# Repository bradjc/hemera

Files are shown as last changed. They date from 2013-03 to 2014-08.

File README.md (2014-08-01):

Hemera Indoor Sensor Node
=========================

Hemera is an indoor wireless sensor node that measures temperature, humidity, light and motion.

The node contains three key sensors:
- Sensirion SHT11 (Temperature and Humidity)
- Rohm BH1721 (Light)
- PIR (Motion)

hemera (http://www.bradcampbell.com/wp-content/uploads/2012/05/hemera_project.jpg)

Setup
-----

### 1) Clone &amp; install the Lab11 version of tinyos-main:

    git clone https://github.com/lab11/tinyos-main.git
    cd tinyos-main/tools
    ./Bootstrap
    ./configure
    make
    sudo make install

### 2) Clone yours truly:

    git clone https://github.com/lab11/hemera.git

### 3) Add to `bash.rc`:

    export TINYOS_ROOT_DIR=<path to>/tinyos-main
    export TINYOS_ROOT_DIR_ADDITIONAL=<path to>/hemera/tinyos:$TINYOS_ROOT_DIR_ADDITIONAL

### 4) Set up the RaspberryPi (optional, but recommended):

A modified RaspberryPi can be utilized to receive and forward data to GATD. 
If you choose to use one, you need the [Linux CC2520 Driver](https://github.com/ab500/linux-cc2520-driver) for the RPi.
Instead of installing this manually, it is suggested to download &amp; install the preinstalled image from [this torrent](https://github.com/lab11/raspberrypi-cc2520/tree/master/torrents).
Go to https://github.com/lab11/raspberrypi-cc2520 for additional details on setup.

Clone the RPi repo:

    git clone https://github.com/lab11/raspberrypi-cc2520.git

Add to `bash.rc`:

    export TINYOS_ROOT_DIR_ADDITIONAL=<path to>/raspberrypi-cc2520/tinyos:$TINYOS_ROOT_DIR_ADDITIONAL

### 5) Get the compilers

In order to compile the TinyOS code you need the msp430 and the ARM compilers

Sense Stuff
-----------

After you have finsihed the above setup, you should be ready to install apps on the Hemera board.

The basic sense &amp; broadcast app is HemeraAM. To install it, go to `<path to>/hemera/tinyos/apps/HemeraAM` and follow the README. 

To receive &amp; forward data to GATD on the RPi, go to `<path to>/hemera/tinyos/apps/RpiGatdForwarder` and follow the README.

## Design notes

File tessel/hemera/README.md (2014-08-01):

Hemera on Tessel
================

Want to implement Hemera on a Tessel? You've come to the right place!  

Requirements
------------

* [Tessel](http://tessel.io)
* [Climate module](https://tessel.io/modules#module-climate)
* [Ambient module](https://tessel.io/modules#module-ambient)
* Standard 3-pin PIR sensor (VCC, GND, OUT)
* [Node.js](http://nodejs.org)

Setup
-----

The assumed module connections are as follows:
- Ambient Module -> Port A
- Climate Module -> Port B
- PIR Sensor -> Port D ( GND -> G1, VCC -> G2, OUT -> G3 )

This, along with HTTP POST destination (default:GATD), can be changed by modifying `hemera.js`.

Installation
------------

If you have yet to do so, [install Node.js & Tessel](http://start.tessel.io/install).

Install the modules:

    npm install ambient-attx4
    npm install climate-si7005
    npm install climate-si7020

Connect to WiFi:

    tessel wifi -n [network name] -p [password]

Run:

    tessel run hemera.js

Save on Tessel to run automatically:

    tessel push hemera.js

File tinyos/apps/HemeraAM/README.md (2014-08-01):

HemeraAM
========
@author Thomas Zachariah
@url    http://github.com/lab11/hemera

Overview
--------

HemeraAM samples temperature, humidity, light, and motion, 
and sends the recorded data via Active Message. 

Installation
------------

Options are located in the Makefile.
Sampling Period & Radio Channel may be adjusted there.

RUN:

    ./install #

(where # is the intended id number of the device) OR

    make hemera install miniprog bsl,/dev/ttyUSB0

When using the install script or the alternate command,
ensure location (`/dev/ttyUSB?`) is correct.

Verification
------------

To verify broadcast, press the user button on the back:
- If the program is running, the green LED will turn on.
- If it is sending packets, the blue LED will toggle.
- If an error is encountered, the red LED will toggle.

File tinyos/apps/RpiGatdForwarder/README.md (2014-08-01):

RpiGatdForwarder
========
@author Thomas Zachariah
@url    http://github.com/lab11/hemera

Overview
--------

RpiGatdForwarder accepts all incoming packets on a channel,
and forwards them to a server (GATD).

Installation
------------

Configure the settings in the Makefile. Then run:

    make rpi install scp.<ip address of the RPi>

Alternatively, you can copy the precompiled app `RpiGatdForwarderC` (runs using default settings) directly to the home directory of the Raspberry Pi.

Run
---

On the Raspberry Pi, run:

    sudo ~/RpiGatdForwarderC

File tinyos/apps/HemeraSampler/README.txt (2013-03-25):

README for a HemeraSampler
@author Brad Campbell
@url http://whereabouts.eecs.umich.edu/wiki/doku.php?id=tinyos_HemeraSampler

** Quick Overview **

HemeraSampler is a straightforward app for using the sensors on the hemera board.
It samples the temperature, humidity, and light sensors. Also reports motion.

Uses Blip 2.0.

** Installation Directions **

The options are located in the Makefile. You can choose how often to sample and
where the packets should be sent to.

make epic blip install miniprog

Run the python mysql listener in $TOSROOT/support/sdk/python/tinyos/listener

** More Info **

http://whereabouts.eecs.umich.edu/wiki/doku.php?id=tinyos_HemeraSampler

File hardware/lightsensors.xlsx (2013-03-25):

Sensor | cost | average current | interface | notes
Si1120 | have (2.64) | 10u | PWM | * pwm length has to be converted to lux, and there aren't equations, just graphs * seems to be designed for its proximity sensing abilities, not ambient light sensing
Avago APDS-9300 | 1.88 (1.65 for 10) | 3.2u sleep, .24m active | i2c Fast-Mode | * controlled by 16 registers that can be written to/read from with i2c * can switch between low gain and high gain * can trigger an interrupt on many different events * have to convert sensor output to "sensor lux" (which is typically == "actual lux")
Rohm BH1721FVC | 2.39 (1.9 for 25) | .01u sleep, .140m active | i2c Fast-Mode | * to use: write an opcode, then issue a read * convert output to lux by dividing by 1.2 * extra async reset port to deal with * no adjustable gain * few different models with varying precision and packages * no interrupt option * have new models that dont need annoying reset, but i can't find them to buy

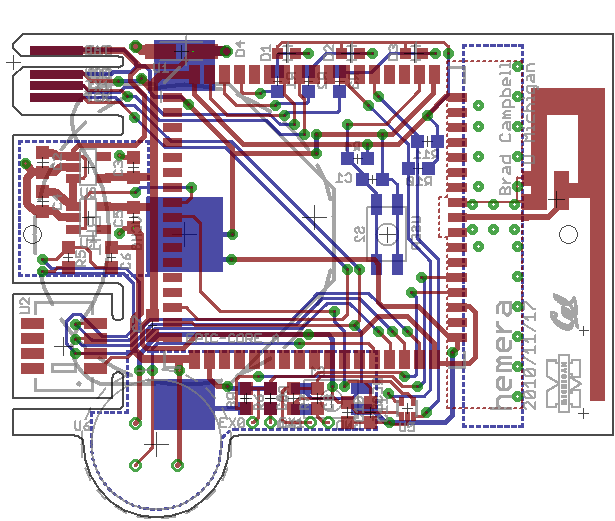
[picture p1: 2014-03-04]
hardware/eagle/rev_c/hemera_C_pcb.png

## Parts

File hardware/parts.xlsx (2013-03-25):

Parts in Hemera (Whereabouts) Box
Part Number | Description | Per | Needed |  |  |  |  |  | Quantity
 |  |  | 10 |  | 25 |  | 50 |  | 2010-11-04 | 2011-03-14 | 2011-08-04 | 2011-10-04
hemera | pcb | 1 | 10 | 0 | 25 | -15 | 50 | -40 |  |  | 10 | 80
MIC5231-3 | 3V Regulator | 1 | 10 | 4 | 25 | -11 | 50 | -36 | 17 | 16 | 14 | 0
MIC5235-3 | 3V Regulator | 1 | 10 | 4 | 25 | -11 | 50 | -36 | 17 | 16 | 14 | 0
SD103AW-TP | 40V Diode | 1 | 10 | 5 | 25 | -10 | 50 | -35 | 16 | 15 | 15 | 9
3008 | battery clip | 1 | 10 | 2 | 25 | -13 | 50 | -38 | 17 | 17 | 12 | 32
10uF | capacitor | 4 | 40 | 185 | 100 | 125 | 200 | 25 | 80 | 83 | 225 | 117
0.1uF | capacitor | 7 | 70 | 230 | 175 | 125 | 350 | -50 | 11 | 164 | 300 | 112
blue | led | 1 | 10 | 2 | 25 | -13 | 50 | -38 | 4 | 3 | 12 | 65
red | led | 1 | 10 | 210 | 25 | 195 | 50 | 170 | 4 | 3 | 220 | 150
green | led | 1 | 10 | 5 | 25 | -10 | 50 | -35 | 5 | 4 | 15 | 65
EVQ-P2K02Q | push switch | 2 | 20 | 3 | 50 | -27 | 100 | -77 | 30 | 28 | 23 | 15
100k | resistor | 3 | 30 | 119 | 75 | 74 | 150 | -1 | 90 | 78 | 149 | 63
10k | resistor | 3 | 30 | 190 | 75 | 145 | 150 | 70 | 95 | 90 | 220 | 130
3M | resistor | 2 | 20 | 140 | 50 | 110 | 100 | 60 | 90 | 83 | 160 | 100
470 | resistor | 3 | 30 | 75 | 75 | 30 | 150 | -45 | 40 | 36 | 105 | 400
BH1721FVC-TR | light sensor | 1 | 10 | 4 | 25 | -11 | 50 | -36 |  | 4 | 14 | 4
SHT11 | sensor | 1 | 10 | -10 | 25 | -25 | 50 | -50 | 1 | 0 | 0 | 1
PIR | sensor | 1 | 10 | -10 | 25 | -25 | 50 | -50 | 1 | 0 | 0 | 1
Epic |  | 1 | 10 | -10 | 25 | -25 | 50 | -50 | 1 | 0 | 0 | 1

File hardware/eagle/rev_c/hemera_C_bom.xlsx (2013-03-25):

Bill of Material - hemera_C
Item # | Quantity | Ref Des | Digi-Key Part Number | Manuf. Part Nr. | Description | Package | Type
1 | 1 | BH1 | 3008K-ND | 3008 | RETAINER COIN CELL 24MM SMD |  | fine-pitch
2 | 7 | C1, C6, C7, C8, C9, C10, C11 |  |  | CAP CER 0.1UF | 0603 | smt
3 | 4 | C2, C3, C4, C5 | 490-3896-1-ND | GRM188R60J106ME47D | CAP CER 10UF 6.3V X5R 0603 | 0603 | smt
4 | 1 | D1 | 638-QTLP600C7 | QTLP600C7TR | RED LED | 0603 | smt
5 | 1 | D2 | P521CT-ND | LNJ308G8LRA | GREEN LED | 0603 | smt
6 | 1 | D3 | LN937W8CRACT-ND | LNJ937W8CRA | BLUE LED | 0603 | smt
7 | 1 | D4 | SD103AWTPMSCT-ND | SD103AW-TP | DIODE SCHOTTKY 40V 350MA SOD123 | custom | fine-pitch
8 | 3 | R1, R2, R3 | P470GCT-ND | ERJ-3GEYJ471V | RES 470 OHM 1/10W 5% 0603 SMD | 0603 | smt
9 | 3 | R4, R6, R7 | P100KGCT-ND | ERJ-3GEYJ104V | RES 100K OHM 1/10W 5% 0603 SMD | 0603 | smt
10 | 3 | R5, R10, R11 | RMCF0603FT10K0CT-ND | RMCF0603FT10K0 | RES 10K OHM 1/10W 1% 0603 SMD | 0603 | smt
11 | 2 | R8, R9 | P3.0MGCT-ND | ERJ-3GEYJ305V | RESISTOR 3.0M OHM 1/10W 5% 0603 | 0603 | smt
12 | 2 | S1, S2 | P11084SCT-ND | EVQ-P2K02Q | LT SWITCH 2.5MM HT 350GF SMD | custom | smt
13 | 1 | U1 |  |  | Epic core |  | smt
14 | 1 | U2 | 69c4848 | SHT11 | SHT11 TEMP?HUMIDITY SENSOR |  | smt
15 | 1 | U3 | 576-1283-1-ND | MIC5231-3.0YM5 TR | IC REG LDO 3.0V MICROPWR SOT23-5 | SOT-23 | fine-pitch
16 | 1 | U4 | 576-2783-1-ND | MIC5235-3.0YM5 TR | IC REG LDO 150MA 3.0V SOT23-5 | SOT-23 | fine-pitch
17 | 1 | U5 | BH1721FVC-CT-ND | BH1721FVC-TR | IC AMBIENT LIGHT SENSOR WSOF5 | WSOF5 | smt
18 | 1 | U6 | 255-2652-ND | AMN42122 | PIR |  | thru-hole
 |  |  |  |  | BOARD SUMMARY FOR QUOTE
 |  |  |  |  | Total # of unique parts | 18
 |  |  |  |  | SMT placements per board | 30
 |  |  |  |  | Thru-hole placements per board | 1
 |  |  |  |  | Fine pitch placements per board | 4

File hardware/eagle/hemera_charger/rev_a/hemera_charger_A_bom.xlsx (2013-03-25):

Bill of Material - hemera_charger_A
Item # | Quantity | Ref Des | Digi-Key Part Number | Manuf. Part Nr. | Description | Package | Type
1 | 4 | C1, C2, C3, C4 |  |  | CAP CER 1UF 0603 | 0603 | smd
2 | 1 | C5 |  |  | CAP CER 10UF 0603 | 0603 | smd
3 | 1 | C6 |  |  | CAP CER 22UF 0603 | 0603 | smd
4 | 1 | C7 |  |  | CAP CER 0.1UF 0603 | 0603 | smd
5 | 2 | R1, R2 |  |  | RES 1K OHM 0603 | 0603 | smd
6 | 1 | R3 |  |  | RES 1.8M OHM 0603 | 0603 | smd
7 | 1 | R4 |  |  | RES 200K OHM 0603 | 0603 | smd
8 | 1 | D1 |  |  | BLUE LED 0603 | 0603 | smd
9 | 1 | D2 |  |  | RED LED 0603 | 0603 | smd
10 | 1 | L1 |  | LPS3015-222ML | INDUCTOR 2.2 uH |  | smd
11 | 2 | U1, U2 | 700-MAX1555EZK+T | MAX1555EZK+T | Dual USB/AC 1-Cell Li+ Battery Charger | SOT23-5 | fine-pitch
12 | 1 | U3 | 296-21663-1-ND | TPS61200DRCT | IC BOOST SYNC ADJ 1.2A 10SON |  | smd
13 | 1 | S1 | EG4631CT-ND | EG1381A | SWITCH SLIDE SP3T L=2.0MM SMD |  | fine-pitch
14 | 1 | B1 | 5169-UBBL19-C1 | UBBL19-C1 | Rechargeable Li-Ion 3.6V 2.4Ah
15 | 2 | J1 | WM17141CT-ND | 47346-0001 | CONN RCPT 5POS MICRO USB R/A |  | smd
 |  |  |  |  | BOARD SUMMARY FOR QUOTE
 |  |  |  |  | Total # of unique parts | 15
 |  |  |  |  | SMT placements per board
 |  |  |  |  | Thru-hole placements per board | 0
 |  |  |  |  | Fine pitch placements per board

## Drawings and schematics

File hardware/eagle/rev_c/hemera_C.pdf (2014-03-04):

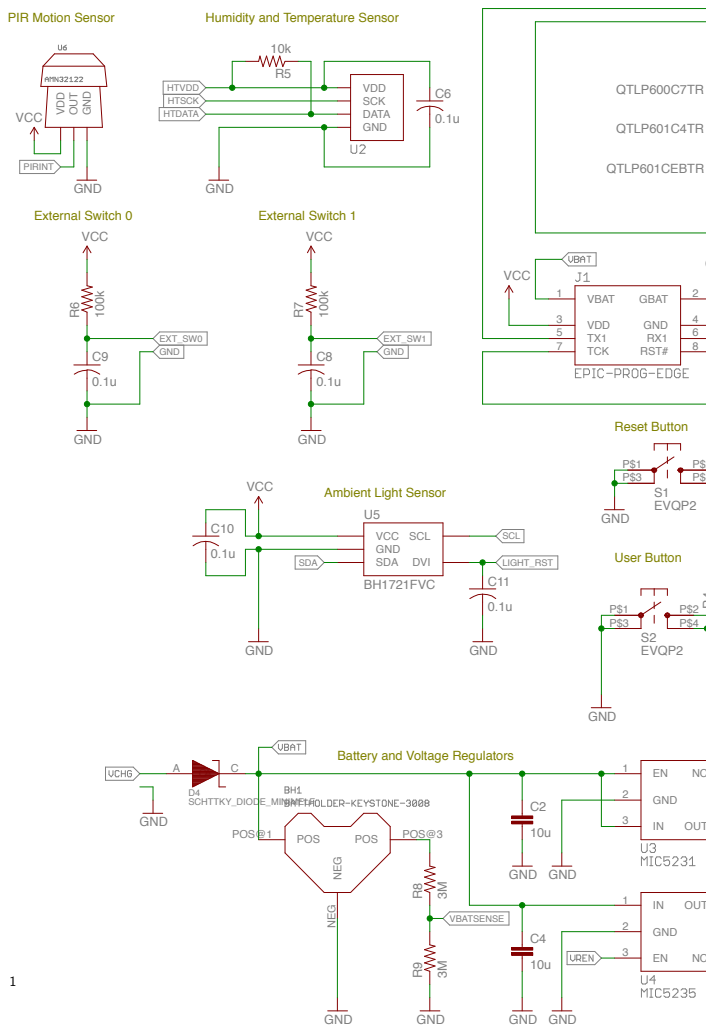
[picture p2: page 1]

Battery and Voltage Regulators

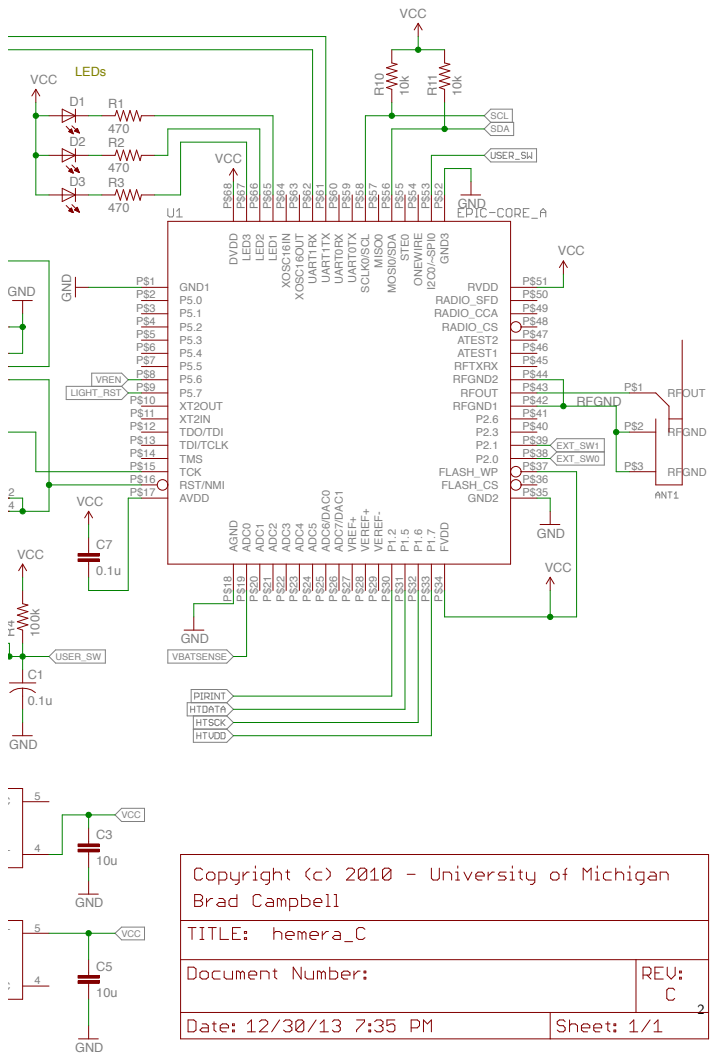
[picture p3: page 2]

## Top and Bottom Layers

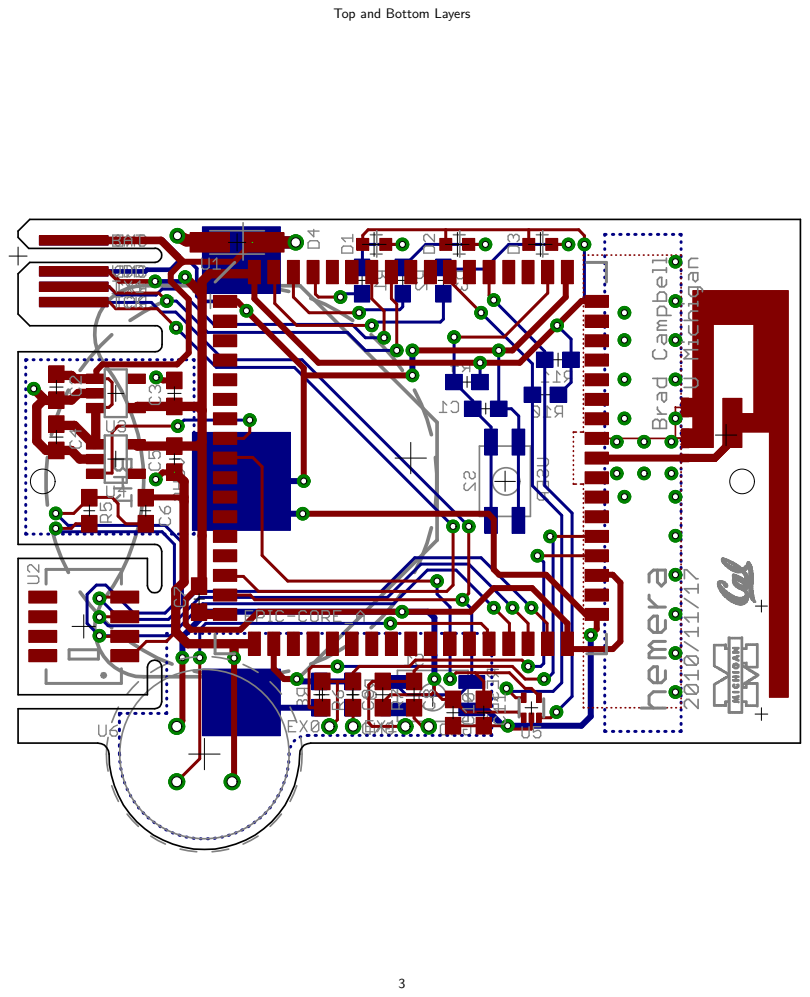
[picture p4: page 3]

## Top Layer

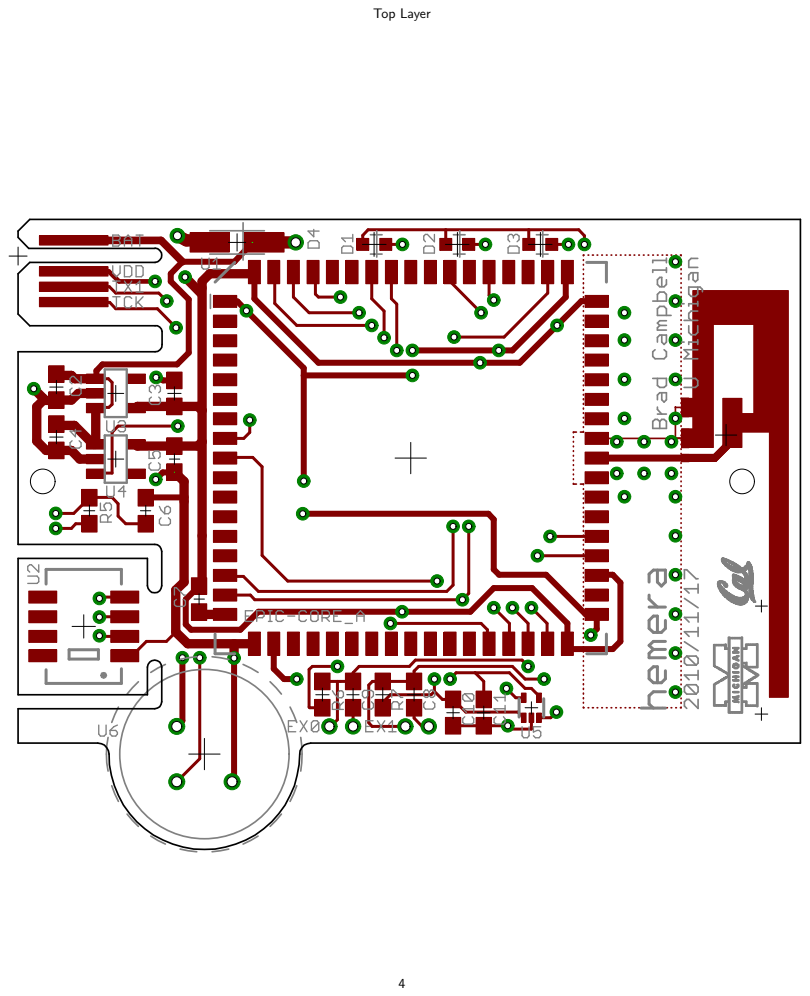
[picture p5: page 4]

## Bottom Layer

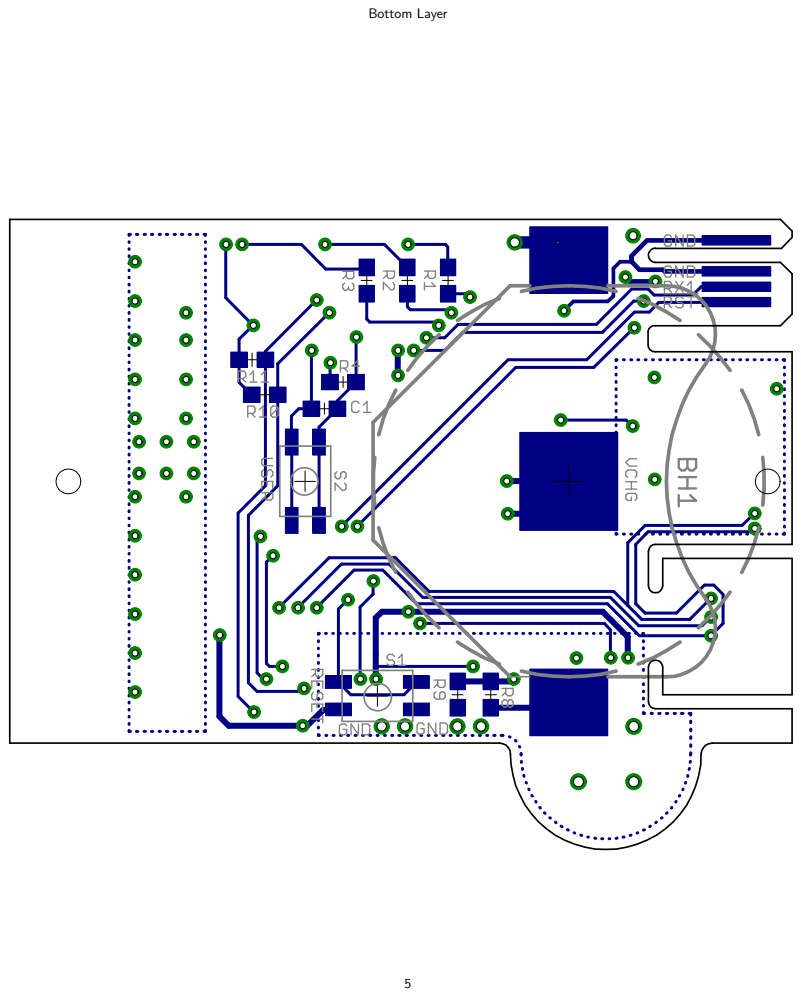
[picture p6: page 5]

## Top Copper Layer

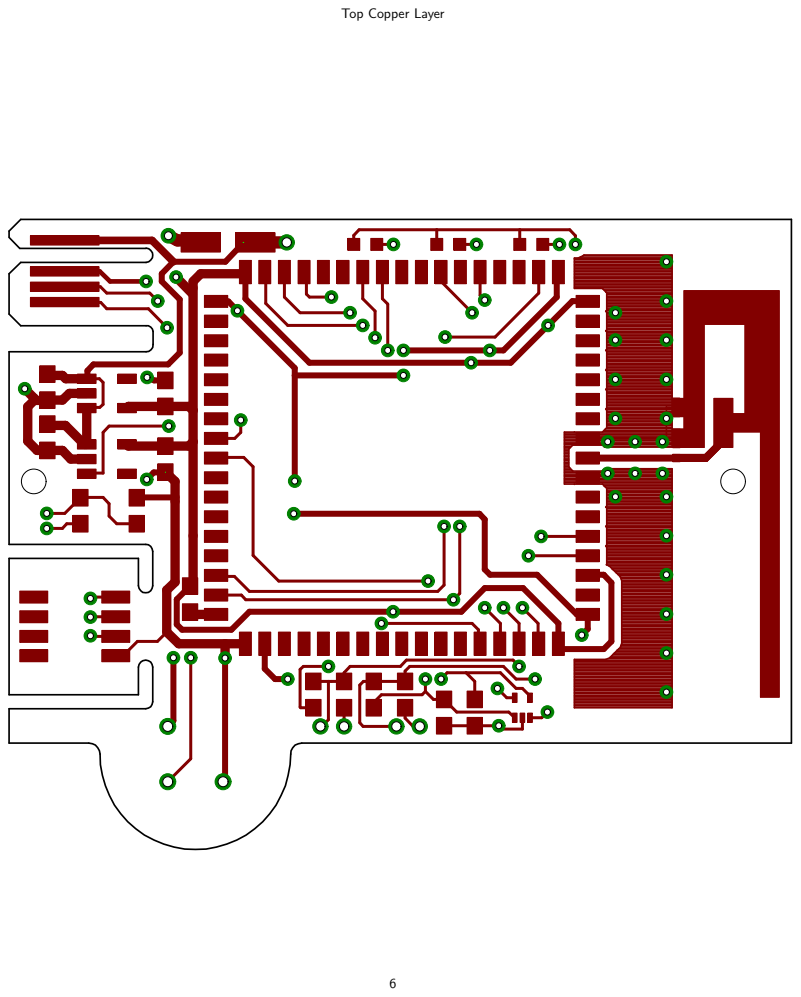
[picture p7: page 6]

## Bottom Copper Layer

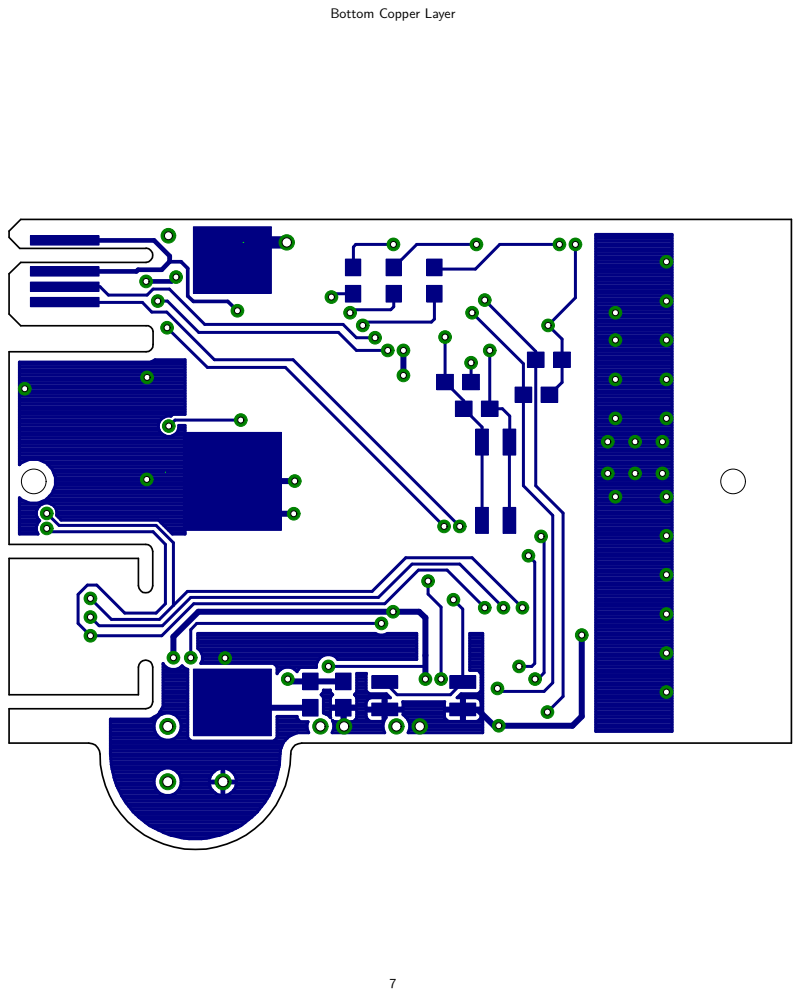
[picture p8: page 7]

## Top Paste Layer with Silkscreen

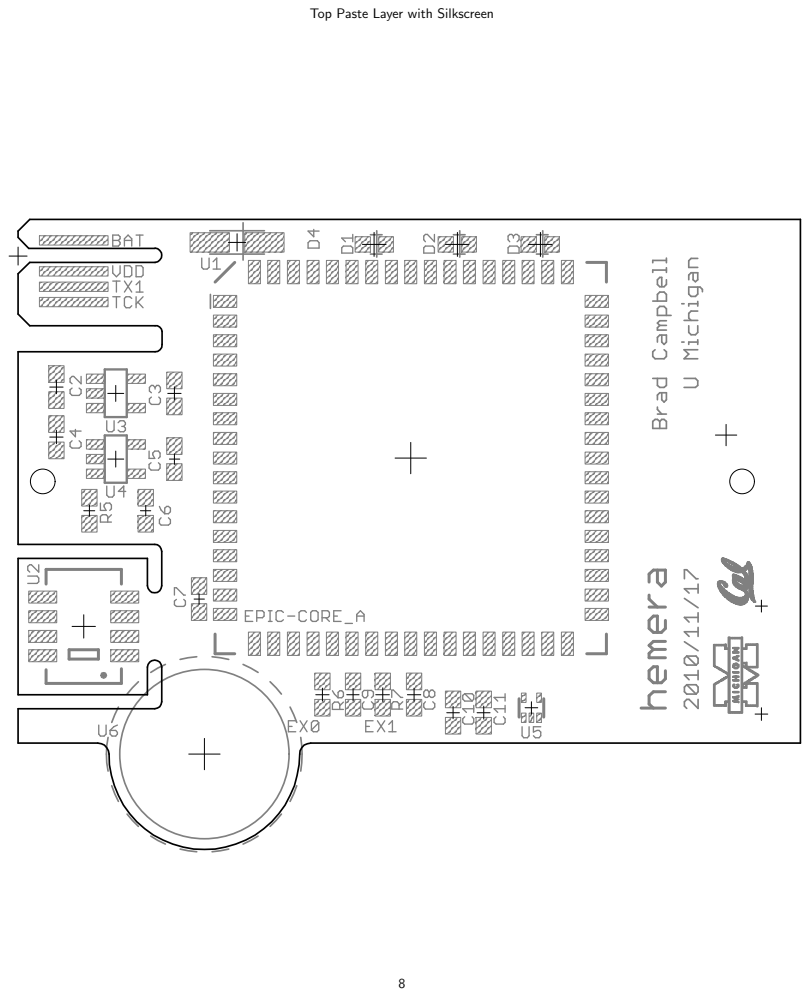
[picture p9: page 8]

## Bottom Paste Layer with Silkscreen

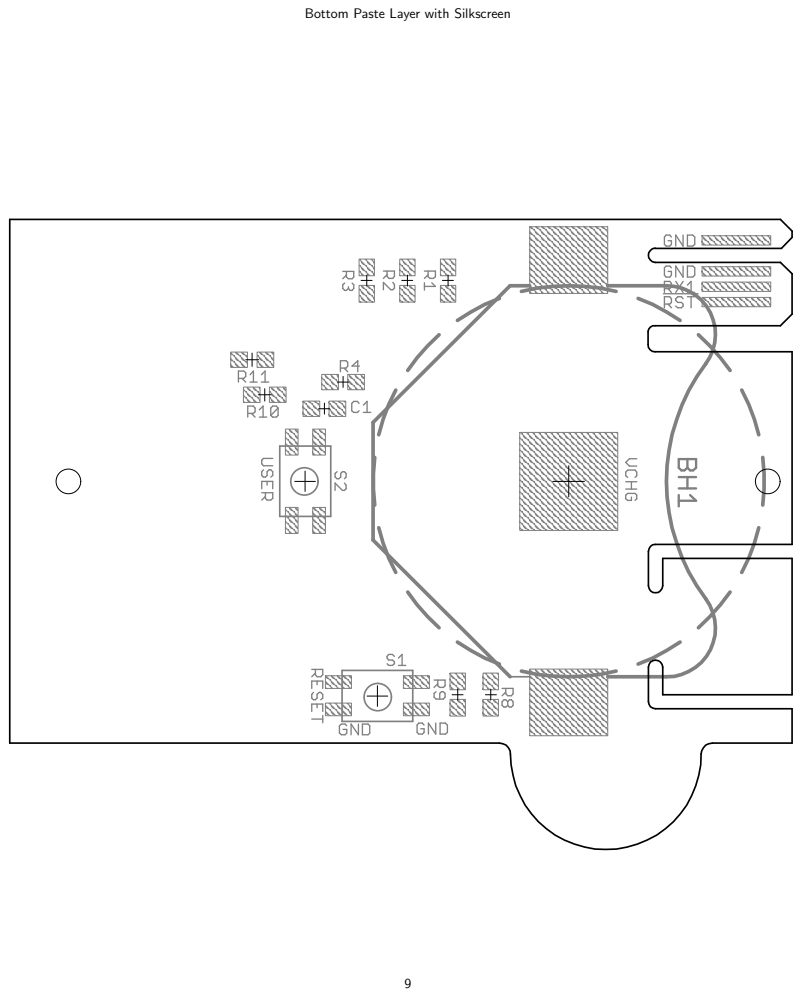
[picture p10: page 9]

## Top and Bottom Layers 1:1 Scale

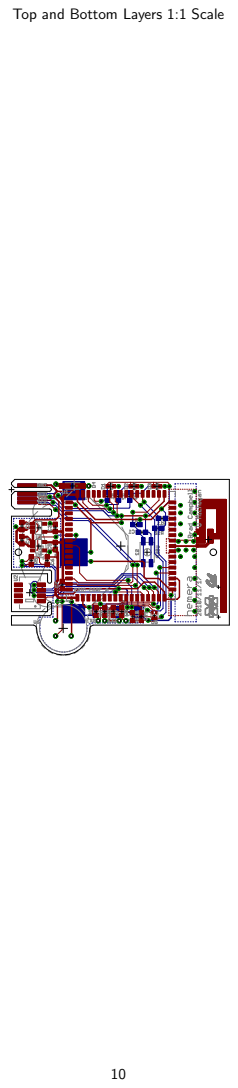
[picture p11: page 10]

## Top Layer 1:1 Scale

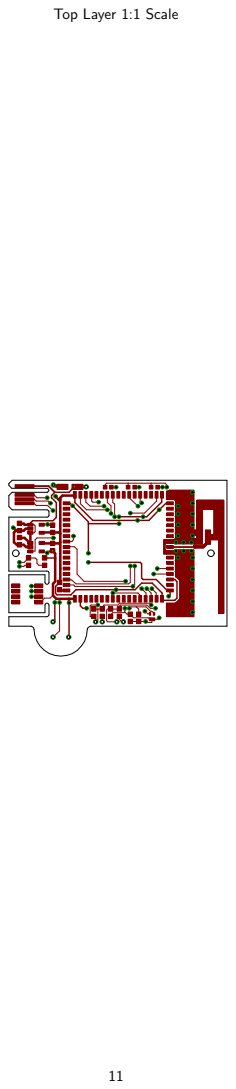
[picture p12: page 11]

## Bottom Copper Layer 1:1 Scale

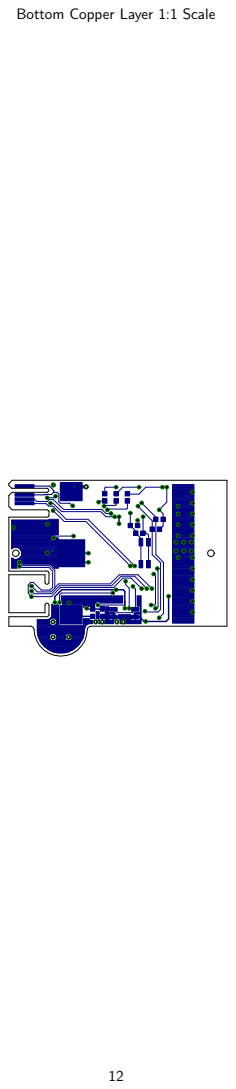
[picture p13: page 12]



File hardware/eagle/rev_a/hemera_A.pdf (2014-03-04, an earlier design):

# VCC100k

# VCC100k


Battery and Voltage Regulators


## Top and Bottom Layers


## Top Layer


## Bottom Layer


## Top Copper Layer


## Bottom Copper Layer


## Top Paste Layer with Silkscreen


## Bottom Paste Layer with Silkscreen


## Top and Bottom Layers 1:1 Scale


## Top Layer 1:1 Scale


## Bottom Copper Layer 1:1 Scale


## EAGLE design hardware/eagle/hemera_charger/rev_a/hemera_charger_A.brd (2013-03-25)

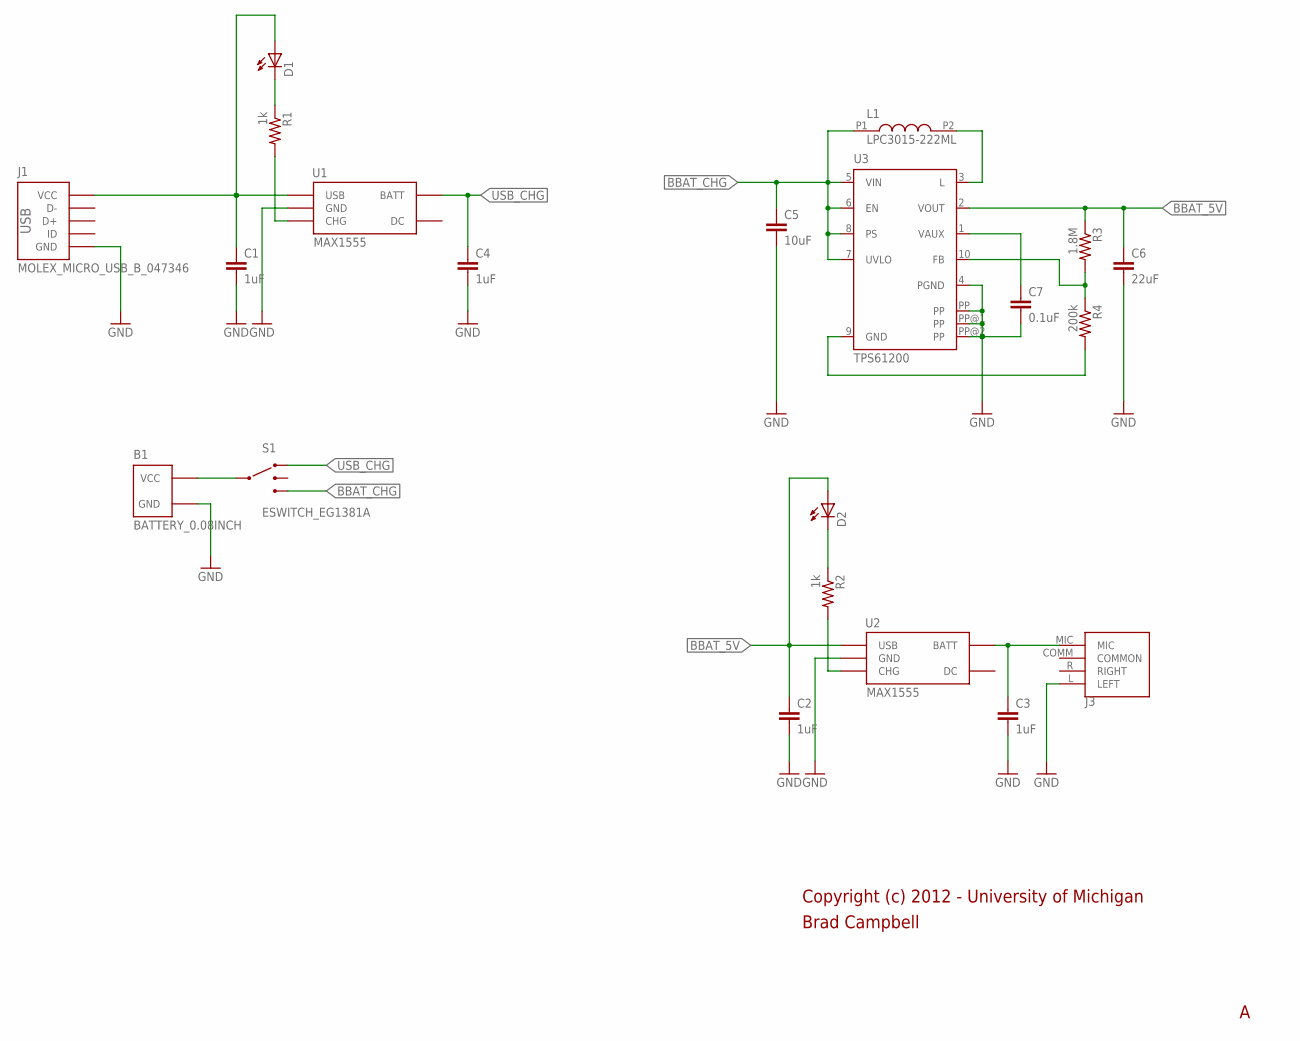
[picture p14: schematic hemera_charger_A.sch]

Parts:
B1: BATTERY_0.08INCH
C1, C2, C3, C4: 1uF; C0603
C5: 10uF; C0603
C6: 22uF; C0603
C7: 0.1uF; C0603
D1, D2: LED0603; LED-0603
J1: MOLEX_MICRO_USB_B_047346
J3: 3.5JACK4CONNSUNSTONE_QUICKTURN; PLUGBOARDCONNECTOR_SUNSTONE
L1: LPC3015-222ML; LPS3015
R1, R2: 1k; R0603
R3: 1.8M; R0603
R4: 200k; R0603
S1: ESWITCH_EG1381A; ESWITCH_EG1381
U1, U2: MAX1555; SOT23-5
U3: TPS61200; S-PDSO-N10

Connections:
BBAT: B1.POS (VCC), S1.3
BBAT_5V: C2.1, C6.1, D2.A, R3.1, U2.1 (USB), U3.2 (VOUT)
BBAT_CHG: C5.1, L1.P1 (1), S1.4, U3.5 (VIN), U3.6 (EN), U3.7 (UVLO), U3.8 (PS)
COMMON: J3.COMM (COMMON)
FB: R3.2, R4.1, U3.10 (FB)
GND: B1.NEG (GND), C1.2, C2.2, C3.2, C4.2, C5.2, C6.2, C7.2, J1.GND, J3.L (LEFT), U1.2 (GND), U2.2 (GND), U3.4 (PGND), U3.PP, U3.PP@1 (PP), U3.PP@2 (PP)
L: L1.P2 (2), U3.3 (L)
unnamed: C1.1, D1.A, J1.VCC, U1.1 (USB)
unnamed: R2.2, U2.3 (CHG)
unnamed: C3.1, J3.MIC, U2.5 (BATT)
unnamed: R1.2, U1.3 (CHG)
unnamed: D1.C, R1.1
unnamed: R4.2, U3.9 (GND)
unnamed: D2.C, R2.1
USB_CHG: C4.1, S1.1, U1.5 (BATT)
VAUX: C7.1, U3.1 (VAUX)

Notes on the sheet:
Brad Campbell
Copyright (c) 2012 - University of Michigan

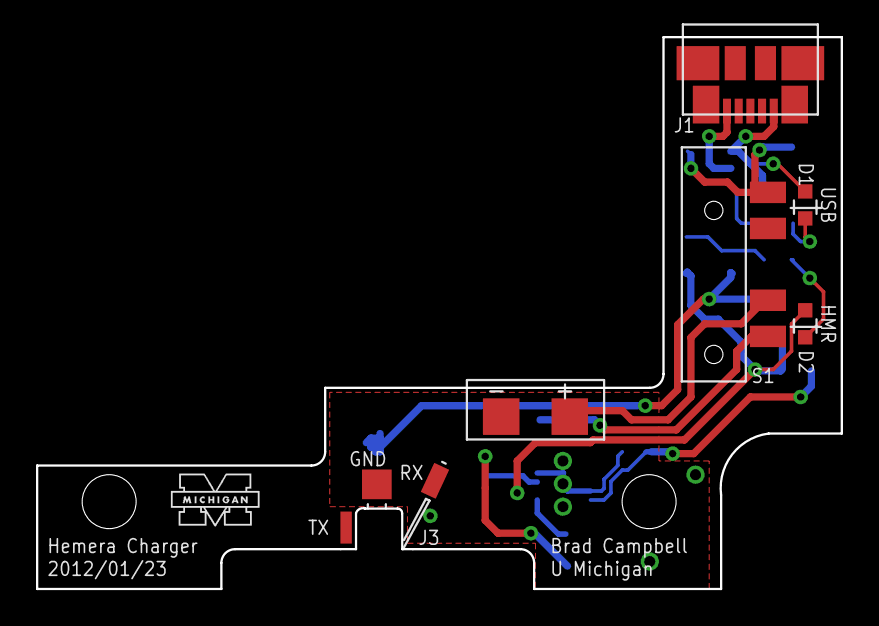
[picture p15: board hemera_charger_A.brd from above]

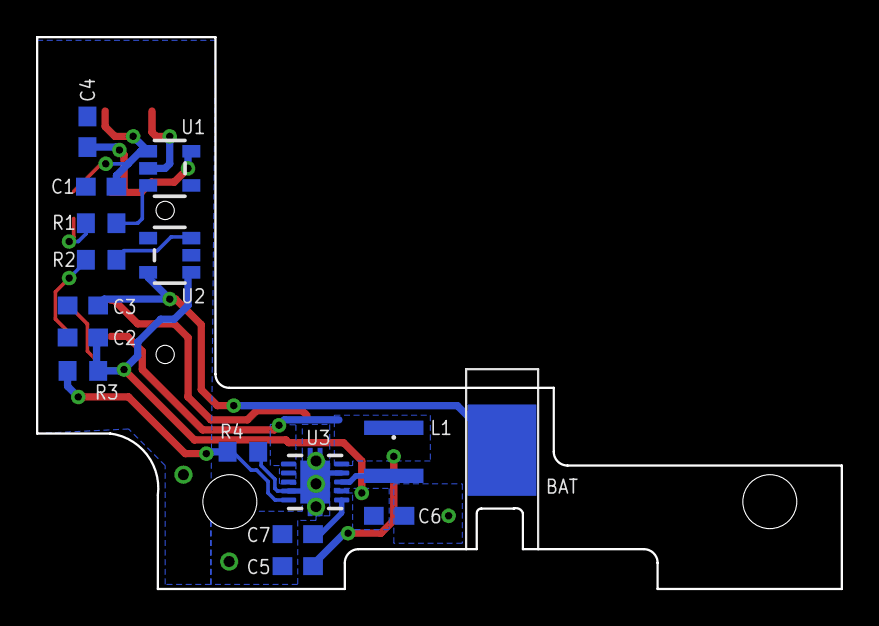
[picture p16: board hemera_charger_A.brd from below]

Board: 2 copper layers, 44.7 x 30.7 mm, 22 parts (15 on the bottom side), 15 nets.

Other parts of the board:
U$1: UMICH

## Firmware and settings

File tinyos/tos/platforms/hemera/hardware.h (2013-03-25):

// $Id: hardware.h,v 1.3 2010-06-29 22:07:52 scipio Exp $

/*
 * Copyright (c) 2007-2008 The Regents of the University of
 * California.  All rights reserved.
 *
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
 * - Redistributions of source code must retain the above copyright
 *   notice, this list of conditions and the following disclaimer.
 * - Redistributions in binary form must reproduce the above copyright
 *   notice, this list of conditions and the following disclaimer in the
 *   documentation and/or other materials provided with the
 *   distribution.
 * - Neither the name of the copyright holders nor the names of
 *   its contributors may be used to endorse or promote products derived
 *   from this software without specific prior written permission.
 *
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
 * Copyright (c) 2004-2005 Intel Corporation
 * All rights reserved.
 *
 * This file is distributed under the terms in the attached
 * INTEL-LICENSE file. If you do not find these files, copies can be
 * found by writing to Intel Research Berkeley, 2150 Shattuck Avenue,
 * Suite 1300, Berkeley, CA, 94704.  Attention: Intel License Inquiry.
 */

/**
 * Hardware definition for the Hemera platform.
 *
 * @author Brad Campbell
 */
#ifndef _H_hardware_h
#define _H_hardware_h

#include "msp430hardware.h"

#warning "platform hardware hemera"
// enum so components can override power saving,
// as per TEP 112.
enum {
  TOS_SLEEP_NONE = MSP430_POWER_ACTIVE,
};

// internal flash is 16 bits in width
typedef uint16_t in_flash_addr_t;
// external flash is 32 bits in width
typedef uint32_t ex_flash_addr_t;

void wait(uint16_t t) {
  for ( ; t > 0; t-- );
}

// LEDS
TOSH_ASSIGN_PIN(RED_LED, 4, 0);
TOSH_ASSIGN_PIN(GREEN_LED, 4, 3);
TOSH_ASSIGN_PIN(YELLOW_LED, 4, 7);

// CC2420 RADIO
TOSH_ASSIGN_PIN(RADIO_CSN, 4, 2);
TOSH_ASSIGN_PIN(RADIO_VREF, 4, 5);
TOSH_ASSIGN_PIN(RADIO_RESET, 4, 6);
TOSH_ASSIGN_PIN(RADIO_FIFOP, 1, 0);
TOSH_ASSIGN_PIN(RADIO_SFD, 4, 1);
TOSH_ASSIGN_PIN(RADIO_GIO0, 1, 3);
TOSH_ASSIGN_PIN(RADIO_FIFO, 1, 3);
TOSH_ASSIGN_PIN(RADIO_GIO1, 1, 4);
TOSH_ASSIGN_PIN(RADIO_CCA, 1, 4);

TOSH_ASSIGN_PIN(CC_FIFOP, 1, 0);
TOSH_ASSIGN_PIN(CC_FIFO, 1, 3);
TOSH_ASSIGN_PIN(CC_SFD, 4, 1);
TOSH_ASSIGN_PIN(CC_VREN, 4, 5);
TOSH_ASSIGN_PIN(CC_RSTN, 4, 6);

// USART0
TOSH_ASSIGN_PIN(SIMO0, 3, 1);
TOSH_ASSIGN_PIN(SOMI0, 3, 2);
TOSH_ASSIGN_PIN(UCLK0, 3, 3);

// USART1
TOSH_ASSIGN_PIN(SIMO1, 5, 1);
TOSH_ASSIGN_PIN(SOMI1, 5, 2);
TOSH_ASSIGN_PIN(UCLK1, 5, 3);

// UART1
TOSH_ASSIGN_PIN(UTXD0, 3, 4);
TOSH_ASSIGN_PIN(URXD0, 3, 5);
TOSH_ASSIGN_PIN(UTXD1, 3, 6);
TOSH_ASSIGN_PIN(URXD1, 3, 7);

// User Interupt Pin
TOSH_ASSIGN_PIN(USERINT, 2, 7);

// FLASH
TOSH_ASSIGN_PIN(FLASH_CS, 4, 4);

// 1-Wire
TOSH_ASSIGN_PIN(ONEWIRE, 2, 4);

// Voltage Regulator
TOSH_ASSIGN_PIN(VOLTAGE_REG, 5, 6);

// PIR Sensor
#define IO_PIR Port12
TOSH_ASSIGN_PIN(PIR, 1, 2);

// SHT11
#define IO_SHT11_VDD Port17
#define IO_SHT11_SCK Port16
#define IO_SHT11_DATA Port15
TOSH_ASSIGN_PIN(SHT11_VDD, 1, 7);
TOSH_ASSIGN_PIN(SHT11_SCK, 1, 6);
TOSH_ASSIGN_PIN(SHT11_DATA, 1, 5);

// Battery Voltage
#define IO_BATTERY_VOLTAGE Port60
TOSH_ASSIGN_PIN(BATTERY_VOLTAGE, 6, 0);

// External Connections
#define IO_EXT0 Port20
#define IO_EXT1 Port21
TOSH_ASSIGN_PIN(EXT0, 2, 0);
TOSH_ASSIGN_PIN(EXT1, 2, 1);

// BH17 Reset Line
#define IO_LIGHT_RST Port57
TOSH_ASSIGN_PIN(LIGHT_RST, 5, 7);

void TOSH_SET_PIN_DIRECTIONS(void)
{
  P3SEL = 0x0E; // set SPI and I2C to mod func
  
  P1DIR = 0xe0;
  P1OUT = 0x00;
  
  P2DIR = 0x7b;
  P2OUT = 0x10;
  
  P3DIR = 0xf1;
  P3OUT = 0x00;
  
  P4DIR = 0xfd;
  P4OUT = 0xdd;
  
  P5DIR = 0xff;
  P5OUT = 0xff;
  
  P6DIR = 0xff;
  P6OUT = 0x00;
}

// need to undef atomic inside header files or nesC ignores the directive
#undef atomic

#endif // _H_hardware_h

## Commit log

2012-02-08 Added a slightly optimized ds2411 driver to the epic chips folder.
    Added new Gecko apps.
2012-02-14 more gecko code for acks: created module that does data acks in theory at a lower level and is more cc2420 driver like
2012-02-27 re-added powercube.target file
2012-02-27 make powercube install works again
2012-03-03 changes to powercube platform, started debugging radio
2012-10-30 starting on raspberry pi platform
2012-11-01 raspberry pi platfrom is a little closer to compiling
2012-11-26 added set done to thermostat pins setting this should allow multiple button presses to work
2012-11-28 added hemera project to shed
    [hemera_A.brd, hemera_A.sch, hemera_B_bom.xlsx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]
2012-11-28 oops forgot two hemera files
    [lightsensors.xlsx, parts.xlsx]
2012-11-30 temp board tweaks
    fixed hemera makefile
    added figures file to jackit
2013-01-10 adding better msp interrupt function
2013-01-14 ignores and a first pass on the tinyos cc2520rpi driver
    I've gotten the cc2520rpi driver to compile...but that's about it. I'm not sure all of the files I created will make it into the final version as I'm not quite sure what is handled in tinyos and what's in the driver. I assume much of what I'm doing now will have to be replaced or moved, but that is OK.
    Oh, and FUCK SVN.
2013-03-09 thin radio driver for coilcube now compiles
2013-03-09 getting closer to having bare cc2420fb driver working with coilcube
2013-03-10 crispy thin fast boot 2420 driver can now send packets
2013-03-25 Start to explaining how to use this device.
2013-03-25 re-wrote bh17 light sensor driver to make more sense now that I know how to write tinyos drivers better
2013-03-25 removing old files from the driver
2013-03-25 nice hpl file for light sensor on hemera
2013-03-25 removing old interface and fixed comments on driver
2013-03-25 cleaned up the hemera sampler app. Made it easier to read and extend
2013-03-25 correct folder tree
    [hemera_A.brd, hemera_A.sch, hemera_B_bom.xlsx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]
2013-12-31 added pcb docs
2014-06-13 Enable user button functionality
